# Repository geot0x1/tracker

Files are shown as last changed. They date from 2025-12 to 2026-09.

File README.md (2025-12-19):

# Revision 1 [R1]

### Known issues

The 3.3V power supply remains disabled by the battery charger, which pulls the EN pin low with the PG pin. It must be inverted using a BJT.  

Battery connector pins is wrong.  

Crystal has wrong footprint.  

Memory footprint is wrong, too big for the part.  

RX and TX lines on GSM connection are swapped.  

Change the programming port to 1.5mm pitch.

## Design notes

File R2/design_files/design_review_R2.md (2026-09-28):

# GPS/GSM Tracker (tracker.kicad_pro) — Design Review, Board Rev R2

**Date:** 2026-09-28
**Analysis run:** `analysis/2026-09-28_2106/` (schematic, PCB, cross-domain, EMC, thermal)

## Issues

| # | Severity | Issue | Detail |
|---|---|---|---|
| 1 | BLOCKER | Sourcing gate fails (SS-001) | Only 2/94 components (D1, L3) carry an MPN; no `datasheets/` directory exists. Every pin-level/electrical claim elsewhere is consistency-only, not datasheet-verified. Must reach ≥50% MPN coverage before ordering. |
| 2 | WARNING | R1 known issue never fixed: U2 flash footprint too big | U2 (GD25QxxxEY / GD25Q256EYIGR) uses `Package_SON:WSON-8-1EP_8x6mm_P1.27mm_EP3.4x4.3mm` — byte-for-byte identical to R1. The designer's own R1 README flagged this as wrong; it was not addressed in R2. |
| 3 | WARNING | R1 known issue never fixed: programming port still 2.0mm pitch | J3 is still `Connector_JST:JST_PH_B5B-PH-SM4-TB_1x05-1MP_P2.00mm_Vertical` in both R1 and R2. README asked for 1.5mm pitch. |
| 4 | WARNING | Battery connector polarity swapped vs. R1 — needs physical check | R1: J6 pin1=`+BAT`, pin2=`GND`. R2: pin1=`GND`, pin2=`+BAT` (deliberate swap, not a mirror side-effect). Correct polarity depends on the physical battery pack's own wiring convention, which isn't derivable from the schematic — confirm against the harness before fab. |
| 5 | WARNING | Q1 has zero thermal vias | Reverse-polarity/load-switch MOSFET (Q1, PowerDI3333-8) has 0 of 5 recommended thermal-pad vias. Will run hotter than necessary under sustained load current. |
| 6 | WARNING | Insufficient thermal vias on U1/U2 | U1 (MCU, QFN-48): 8/15 recommended. U2 (flash, WSON-8): 4/9 recommended. Low urgency at the board's modeled 0.067W dissipation, but cheap to fix now. |
| 7 | WARNING | No fiducials on either SMD side (FD-001) | Both F.Cu (50 SMD parts) and B.Cu (42 SMD parts) carry fine-pitch parts (U1 QFN-48 @0.5mm pitch, U12 LGA-12 @0.5mm pitch) with zero fiducials. Add ≥3 per side before ordering assembly. |
| 8 | WARNING | J5 (SIM socket) has no ESD protection | Genuinely user-exposed, hot-pluggable connector with no TVS array on CLK/IO/RST/VCC. Also flagged at a 5:1 signal-to-ground pin ratio (only 1 GND reference for 5 signal/power pins). |
| 9 | WARNING | U11 PCB value field wrong (XV-002) | Schematic value is correctly "BQ25622E"; PCB footprint's value property reads "Untitled_1". Risks wrong-part confusion if a BOM is ever generated from PCB properties. |
| 10 | WARNING | Keepout zones sit under U1 and U12 | Two "no copper pour" zones: one (62.0mm², F.Cu) spans U1 (MCU) and its crystal load-cap/pull-up network (C1–C4, R18–R20); another (6.25mm², B.Cu) spans U12 (accelerometer) and nearby passives (C8/C9/C31/C42, L3, R5/R6, U10). Excludes ground pour from directly under the MCU's decoupling/crystal network unless intentional (e.g. RF/antenna keepout) — confirm design intent before fab. |
| 11 | WARNING | Board-edge clearance below safe minimum | R1 (0.28mm) and D1 (0.31mm) are at/below the ~0.3mm typical safe minimum. |
| 12 | WARNING | EMC: switching harmonics in VHF bands (SW-001) | U8 (LMR51430, 500kHz) harmonics land in the 30–88MHz and 88–216MHz VHF bands. Direct overlap with GNSS L1 (1575.42MHz) or GSM/LTE receive bands is unlikely, but low-VHF radiation from board edges is possible. |
| 13 | WARNING | EMC: filter cutoff too close to switching frequency (EF-001) | Reported for both U8 and U9 — filter component values should be revisited against each regulator's actual switching frequency (500kHz is `freq_source=topology_default`, i.e. assumed, not datasheet-confirmed). |
| 14 | WARNING | EMC: large hot loop on U9 (SW-003) | Switch-node loop area for U9 flagged as large — worth a layout pass to tighten it. |
| 15 | WARNING | EMC: L3 proximity to RTC crystal (ML-001) | L3 (assumed unshielded) sits 13.6mm from Y1 (32.768kHz crystal) — plausible minor coupling risk into the RTC crystal at low urgency given the distance and low switching current. |
| 16 | WARNING | EMC: split ground/power plane stackup (SU-001, GP-001) | All 4 copper layers are typed `signal` rather than having a dedicated GND/PWR plane pair; GND is pour-filled per layer but shared/split with +3V3/+VSYS/+5V zones rather than a continuous reference plane. Return-path continuity is not guaranteed as clean as a classic signal/GND/PWR/signal stackup. Stitching (458 vias present) mitigates this but isn't independently confirmed under the OCTOSPI bus or GSM UART traces. |
| 17 | WARNING | U9 regulator Vref is a heuristic guess, not verified | AP61100Z6 is not in the ~60-family Vref lookup table; the assumed 0.6V reference (giving est. 3.3V output via R13/R14) is plausible but unconfirmed — a wrong assumption here would produce a wrong core rail. |
| 18 | WARNING | BG96 (M1) thermal/current behavior is unmodeled | Classified `type=other` by the analyzer, so it's excluded from every power/thermal model. BG96 GSM transmit bursts are the largest realistic heat/current-transient source on the board and are invisible to this review's tooling — manual check against Quectel's hardware design guide is required. |
| 19 | SUGGESTION | Zero test points (TE-001) | 0 of 149 nets have a dedicated test point. Add test points on key rails (+VBAT, +VSYS, +3V3, +5V, GND) for bring-up/production test. |
| 20 | SUGGESTION | EN pull-ups unusually high (PU-001) | R8/R12 (200kΩ) pull-ups on U8/U9 EN pins are high-impedance — plausible intentional choice for sleep-current minimization, but confirm against each regulator's EN pin leakage spec once datasheets are available. |
| 21 | SUGGESTION | J3/J4 have no ESD protection | Lower risk than J5 (J3 is a board-internal debug header; J4 is an RF path where a TVS would degrade matching), but worth a conscious decision either way. |
| 22 | SUGGESTION | Crystal load caps not verified against spec | C1–C4 (18pF) not checked against Y1/Y3's specific CL requirement — no MPN/datasheet available for either crystal. |

## Not Performed / Review Limits

- Datasheet sync/extraction: not performed (no `datasheets/` directory, no MPNs beyond D1/L3) — every pin-level claim above is consistency-only, not datasheet-verified.
- SPICE simulation: not performed (no ngspice/ltspice/xyce installed).
- Lifecycle audit: not performed (no network/API credentials, and MPN coverage too low to be useful).
- Gerber/drill analysis: not applicable (no gerber export in the project).

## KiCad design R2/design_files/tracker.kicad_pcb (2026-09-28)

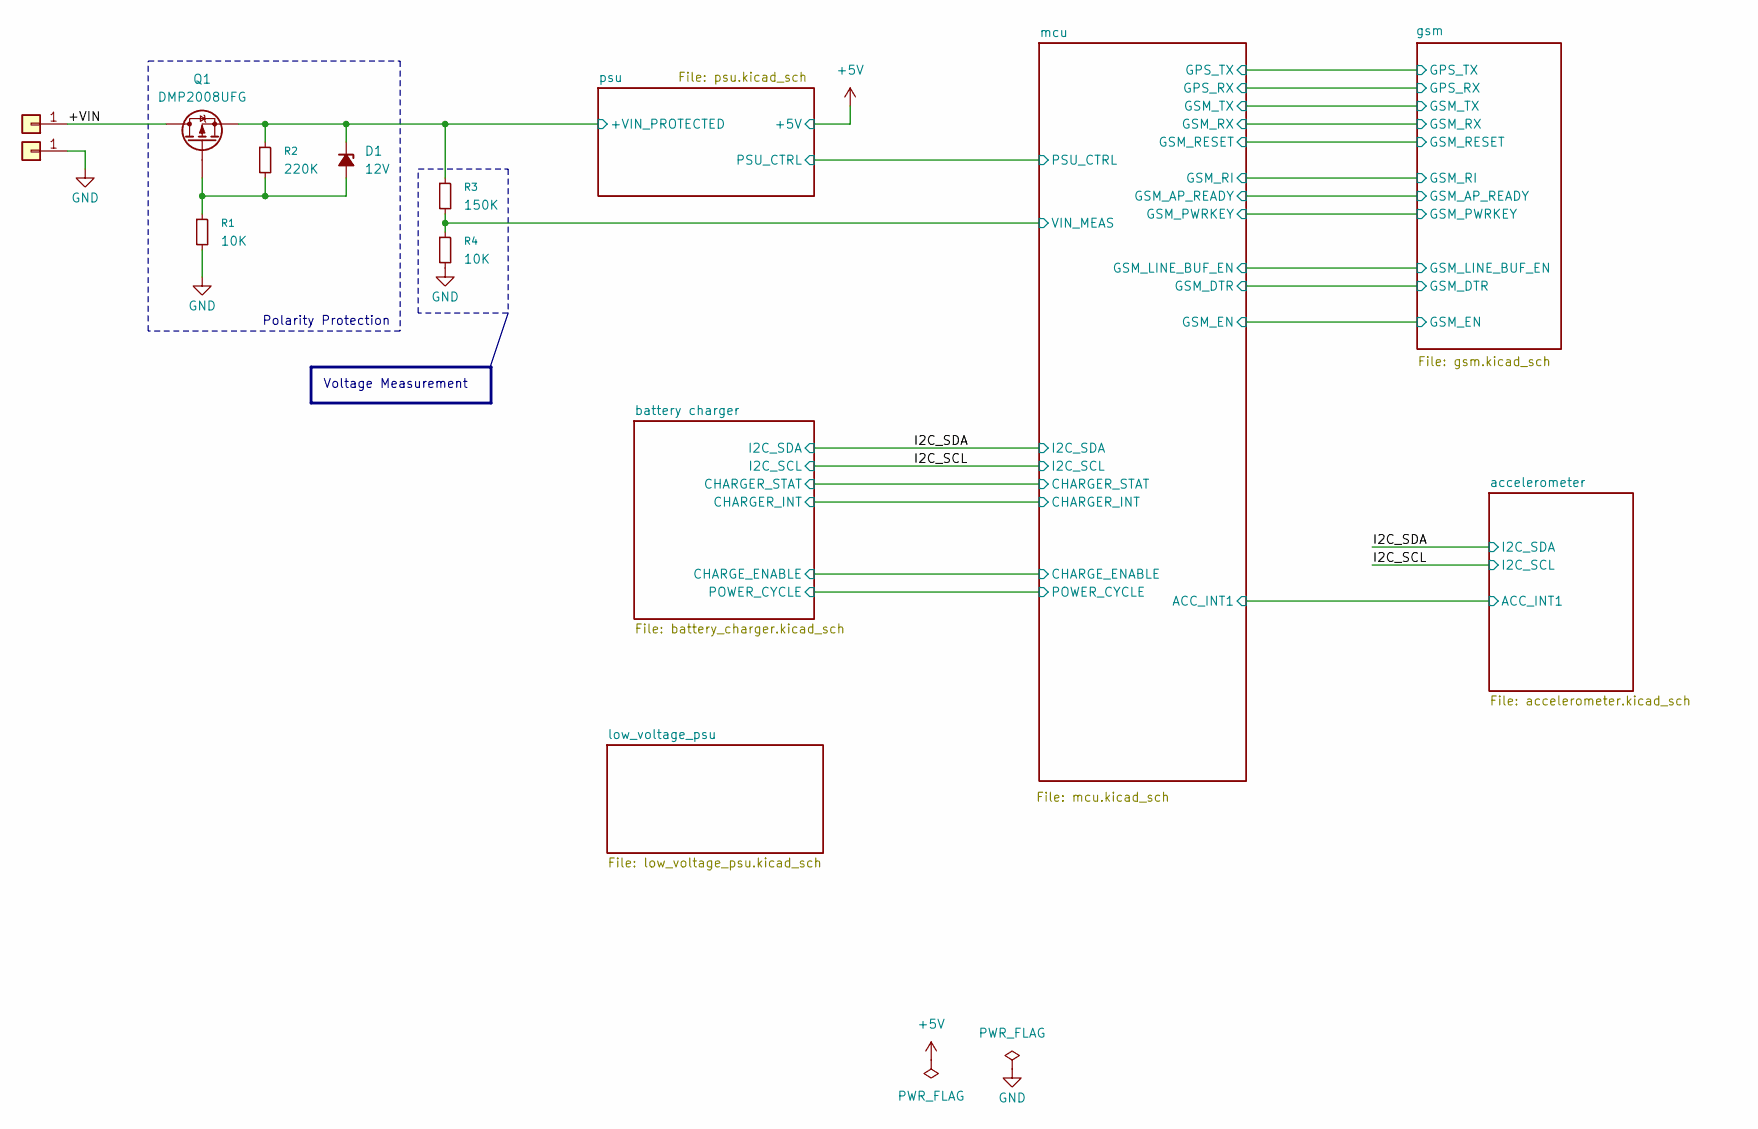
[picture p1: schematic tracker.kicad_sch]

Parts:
D1: 12V; D_SOD-323; PartNo PDZ12B,115
J1, J2: Conn_01x01; pad_smd_1.5x3
Q1: DMP2008UFG; Diodes_PowerDI3333-8
R1, R4: 10K; R_0603_1608Metric
R2: 220K; R_0603_1608Metric
R3: 150K; R_0603_1608Metric

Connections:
/+VIN: J1.1 (Pin_1_1), Q1.5 (D)
/mcu/VIN_MEAS: R3.2, R4.1; also elsewhere on the board
/psu/+VIN_PROTECTED: D1.1 (K), Q1.1 (S), Q1.2 (S), Q1.3 (S), R2.1, R3.1; also elsewhere on the board
GND: J2.1 (Pin_1_1), R1.2, R4.2; also elsewhere on the board
unnamed: D1.2 (A), Q1.4 (G), R1.1, R2.2

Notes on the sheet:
Polarity Protection
Voltage Measurement

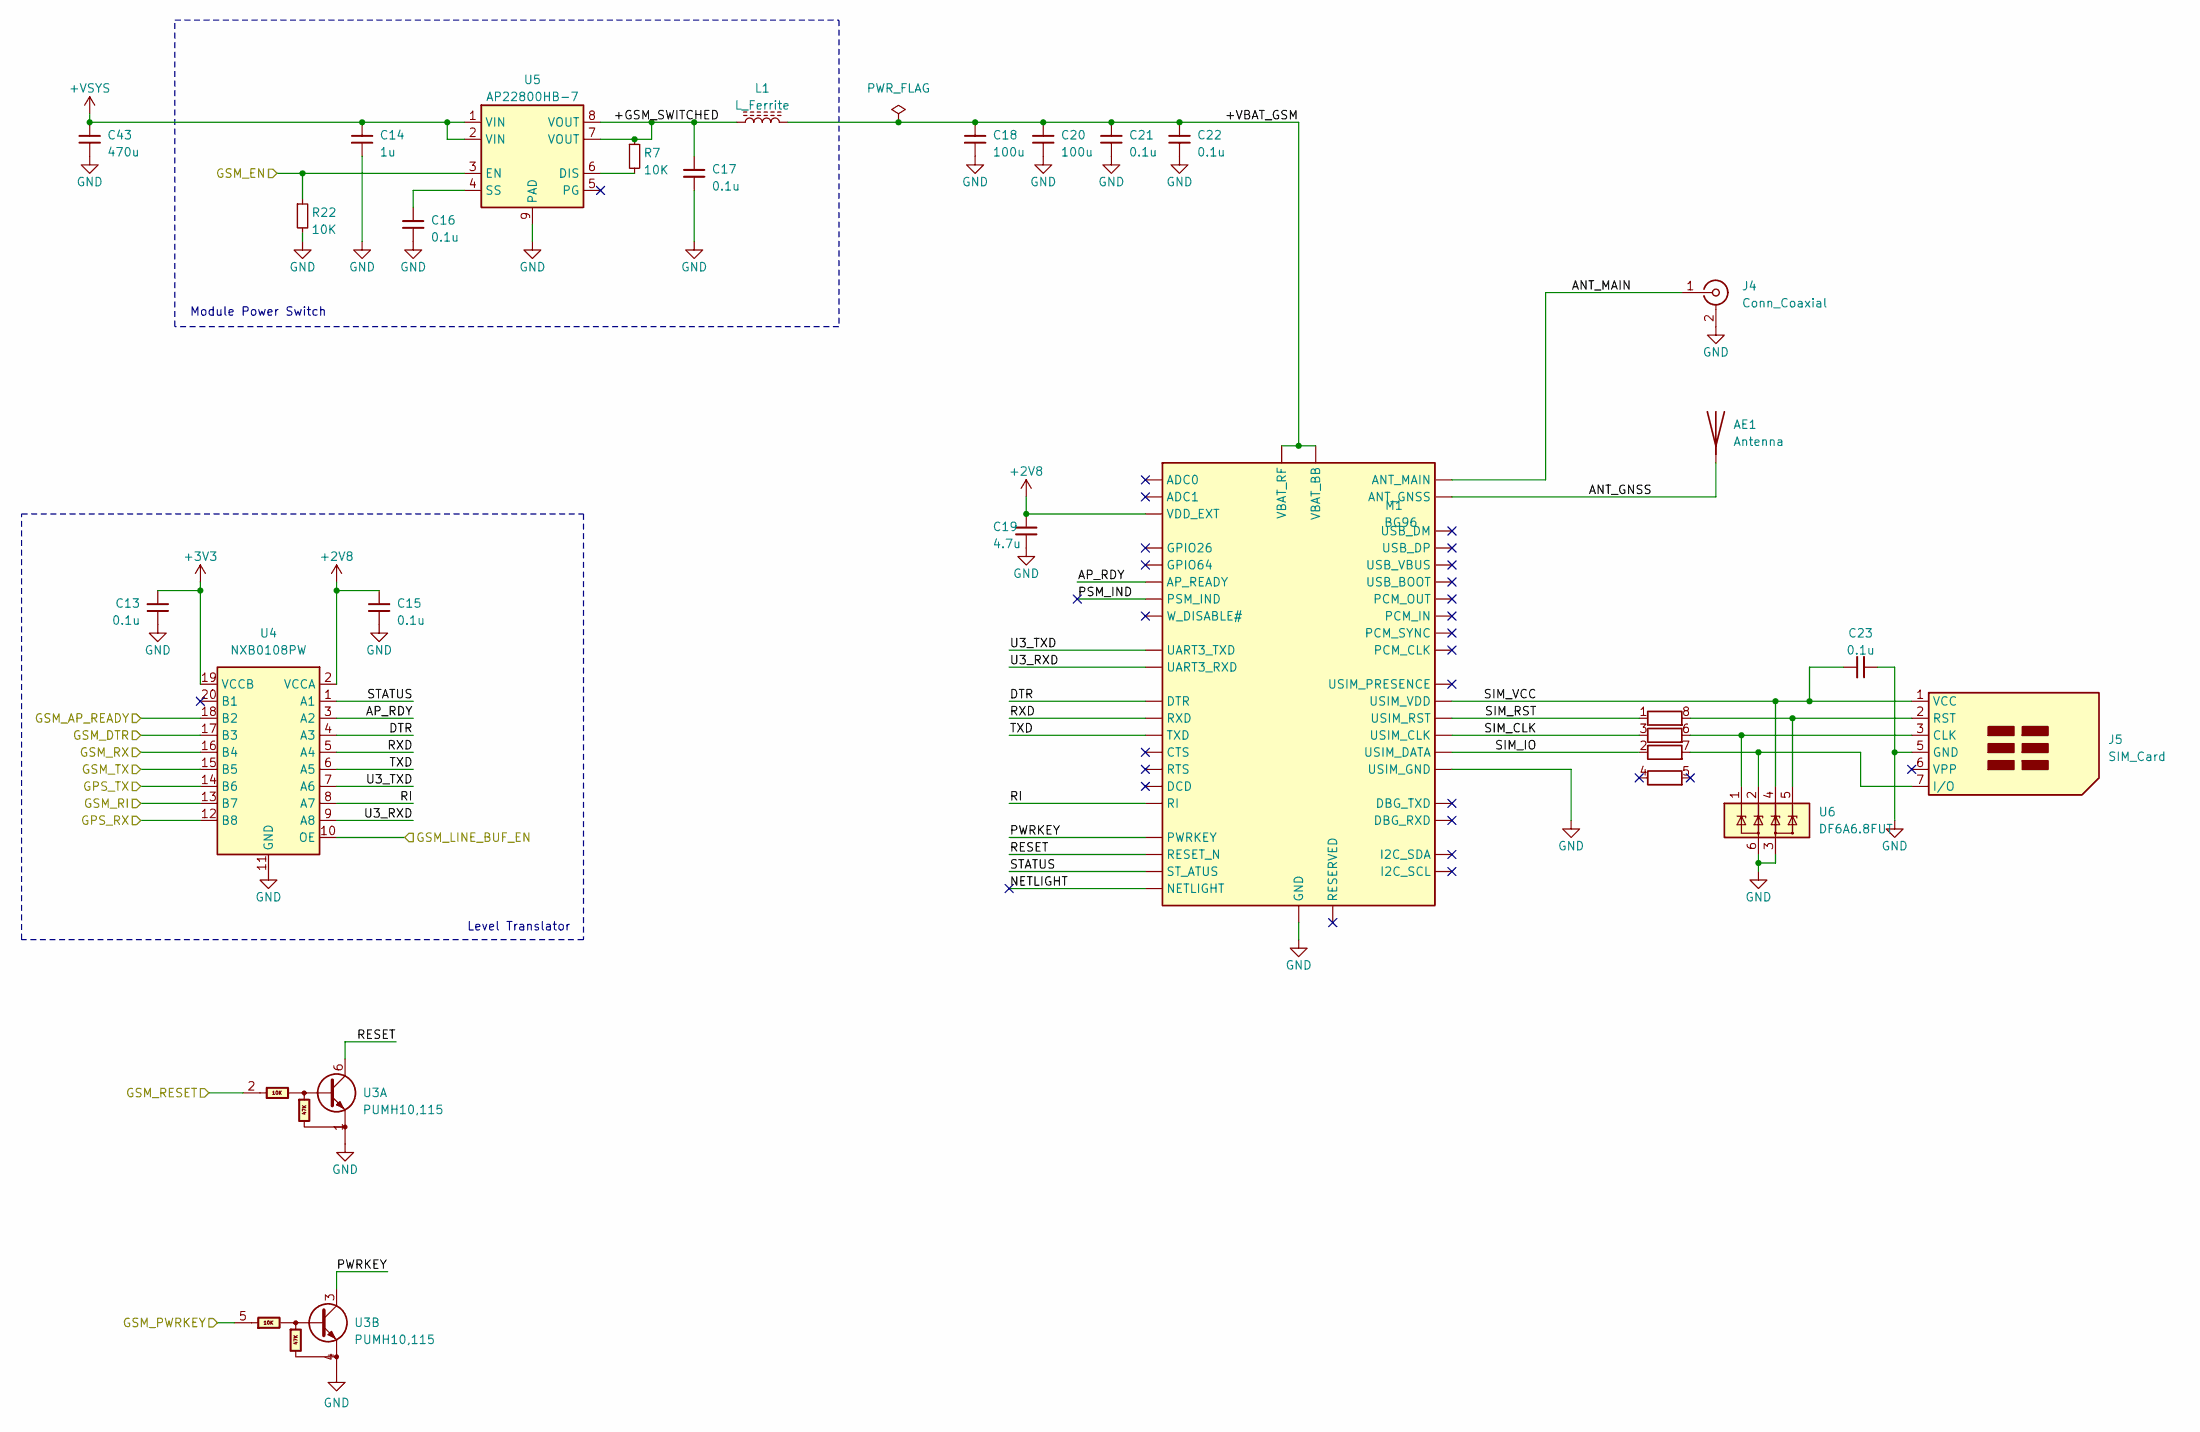
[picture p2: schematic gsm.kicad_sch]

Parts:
AE1: Antenna; APAE1575R1820ABDC1
C13, C15, C16, C17, C21, C22, C23: 0.1u; C_0603_1608Metric
C14: 1u; C_0603_1608Metric
C18, C20: 100u; CP_EIA-6032-20_AVX-F
C19: 4.7u; C_0603_1608Metric
C43: 470u; CP_EIA-7343-31_Kemet-D
J4: Conn_Coaxial; U.FL_Molex_MCRF_73412-0110_Vertical
J5: SIM_Card; microSIM_JAE_SF53S006VCBR2000
L1: L_Ferrite; L_0805_2012Metric
M1: BG96; LGA_BG96
R7, R22: 10K; R_0402_1005Metric
RN1: 22R; R_Array_Concave_4x0603
U3: PUMH10,115; SOT-363_SC-70-6
U4: NXB0108PW; TSSOP-20_4.4x6.5mm_P0.65mm
U5: AP22800HB-7; UDFN2116-8_Diodes
U6: DF6A6.8FUT; SOT-363_SC-70-6

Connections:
+2V8: C15.1, C19.1, M1.29 (VDD_EXT), U4.2 (VCCA)
+3V3: C13.1, U4.19 (VCCB); also elsewhere on the board
+VSYS: C14.1, C43.1, U5.1 (VIN), U5.2 (VIN); also elsewhere on the board
/gsm/+GSM_SWITCHED: C17.1, L1.1, R7.1, U5.7 (VOUT), U5.8 (VOUT)
/gsm/+VBAT_GSM: C18.1, C20.1, C21.1, C22.1, L1.2, M1.32 (VBAT_BB), M1.33 (VBAT_BB), M1.52 (VBAT_RF), M1.53 (VBAT_RF), M1.[32,33] (VBAT_BB), M1.[52,53] (VBAT_RF)
/gsm/ANT_GNSS: AE1.1 (A_1), M1.49 (ANT_GNSS)
/gsm/ANT_MAIN: J4.1 (In), M1.60 (ANT_MAIN)
/gsm/AP_RDY: M1.19 (AP_READY), U4.3 (A2)
/gsm/DTR: M1.30 (DTR), U4.4 (A3)
/gsm/GPS_RX: U4.12 (B8); also elsewhere on the board
/gsm/GPS_TX: U4.14 (B6); also elsewhere on the board
/gsm/GSM_AP_READY: U4.18 (B2); also elsewhere on the board
/gsm/GSM_DTR: U4.17 (B3); also elsewhere on the board
/gsm/GSM_EN: R22.1, U5.3 (EN); also elsewhere on the board
/gsm/GSM_LINE_BUF_EN: U4.10 (OE); also elsewhere on the board
/gsm/GSM_PWRKEY: U3.5; also elsewhere on the board
/gsm/GSM_RESET: U3.2; also elsewhere on the board
/gsm/GSM_RI: U4.13 (B7); also elsewhere on the board
/gsm/GSM_RX: U4.16 (B4); also elsewhere on the board
/gsm/GSM_TX: U4.15 (B5); also elsewhere on the board
/gsm/NETLIGHT: M1.21 (NETLIGHT)
/gsm/PSM_IND: M1.1 (PSM_IND)
/gsm/PWRKEY: M1.15 (PWRKEY), U3.3
/gsm/RESET: M1.17 (RESET_N), U3.6
/gsm/RI: M1.39 (RI), U4.8 (A7)
/gsm/RXD: M1.34 (RXD), U4.5 (A4)
/gsm/SIM_CLK: M1.46 (USIM_CLK), RN1.3 (R3.1)
/gsm/SIM_IO: M1.45 (USIM_DATA), RN1.2 (R2.1)
/gsm/SIM_RST: M1.44 (USIM_RST), RN1.1 (R1.1)
/gsm/SIM_VCC: C23.1, J5.1 (VCC), M1.43 (USIM_VDD), U6.4 (IO3)
/gsm/STATUS: M1.20 (ST_ATUS), U4.1 (A1)
/gsm/TXD: M1.35 (TXD), U4.6 (A5)
/gsm/U3_RXD: M1.28 (UART3_RXD), U4.9 (A8)
/gsm/U3_TXD: M1.27 (UART3_TXD), U4.7 (A6)
GND: C13.2, C14.2, C15.2, C16.2, C17.2, C18.2, C19.2, C20.2, C21.2, C22.2, C23.2, C43.2, J4.2 (Ext), J5.5 (GND), M1.3 (GND), M1.31 (GND), M1.47 (USIM_GND), M1.48 (GND), M1.50 (GND), M1.54 (GND), M1.55 (GND), M1.58 (GND), M1.59 (GND), M1.61 (GND), M1.62 (GND), M1.67 (GND), M1.68 (GND), M1.69 (GND), M1.70 (GND), M1.71 (GND), M1.72 (GND), M1.73 (GND), M1.74 (GND), M1.79 (GND), M1.80 (GND), M1.81 (GND), M1.82 (GND), M1.89 (GND), M1.90 (GND), M1.91 (GND), M1.100 (GND), M1.101 (GND), M1.102 (GND), M1.[3,31,48,50,54,55,5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 (GND), R22.2, U3.1, U3.4, U4.11 (GND), U5.9 (PAD), U6.3 (GND), U6.6 (GND); also elsewhere on the board
unnamed: J5.3 (CLK), RN1.6 (R3.2), U6.1 (IO1)
unnamed: J5.7 (I/O), RN1.7 (R2.2), U6.2 (IO2)
unnamed: J5.2 (RST), RN1.8 (R1.2), U6.5 (IO4)
unnamed: R7.2, U5.6 (DIS)
unnamed: C16.1, U5.4 (SS)

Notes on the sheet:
Module Power Switch
Level Translator

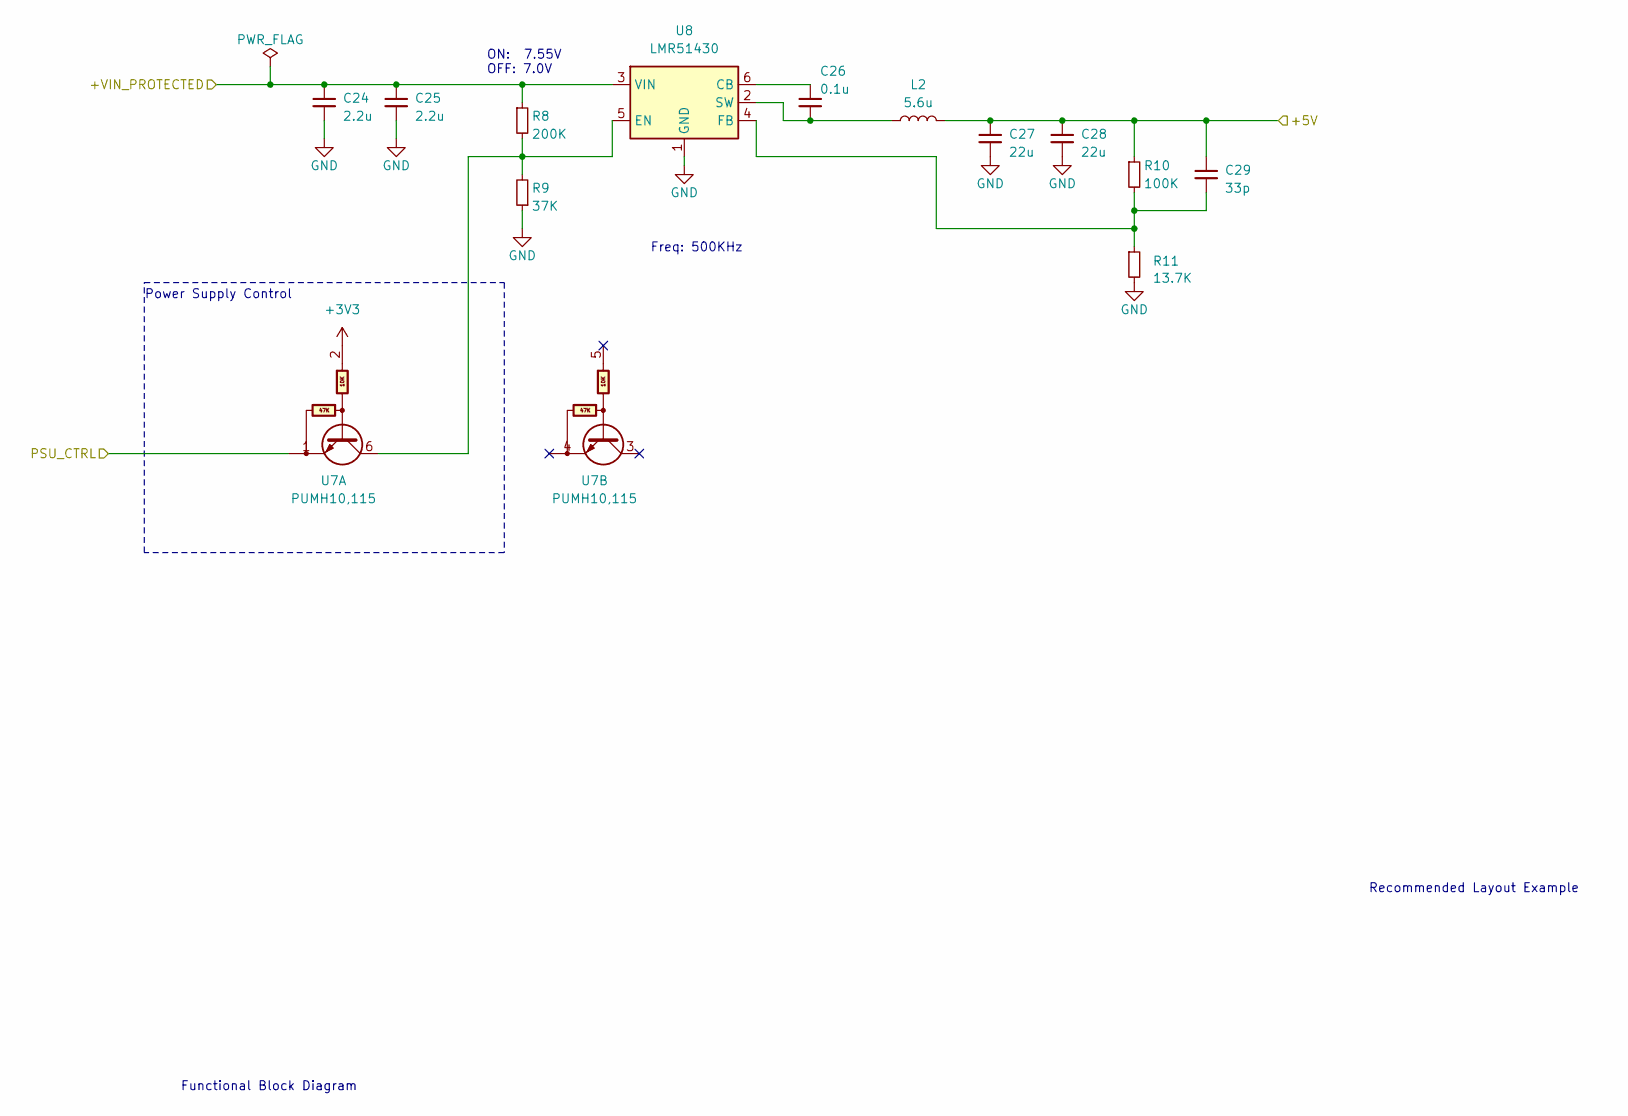
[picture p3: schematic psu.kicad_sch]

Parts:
C24, C25: 2.2u; C_1210_3225Metric
C26: 0.1u; C_0603_1608Metric
C27, C28: 22u; C_1210_3225Metric
C29: 33p; C_0402_1005Metric
L2: 5.6u; L_Bourns_SRN8040TA; Part No SRN8040TA-5R6M
R8: 200K; R_0402_1005Metric
R9: 37K; R_0402_1005Metric
R10: 100K; R_0402_1005Metric
R11: 13.7K; R_0402_1005Metric
U7: PUMH10,115; SOT-363_SC-70-6
U8: LMR51430; SOT-23-6

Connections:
+3V3: U7.2; also elsewhere on the board
+5V: C27.1, C28.1, C29.1, L2.2, R10.1; also elsewhere on the board
/mcu/PSU_CTRL: U7.1; also elsewhere on the board
/psu/+VIN_PROTECTED: C24.1, C25.1, R8.1, U8.3 (VIN); also elsewhere on the board
GND: C24.2, C25.2, C27.2, C28.2, R9.1, R11.2, U8.1 (GND); also elsewhere on the board
unnamed: C26.1, U8.6 (CB)
unnamed: R8.2, R9.2, U7.6, U8.5 (EN)
unnamed: C29.2, R10.2, R11.1, U8.4 (FB)
unnamed: C26.2, L2.1, U8.2 (SW)

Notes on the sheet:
Freq: 500KHz
Functional Block Diagram
ON: 7.55V OFF: 7.0V
Power Supply Control
Recommended Layout Example

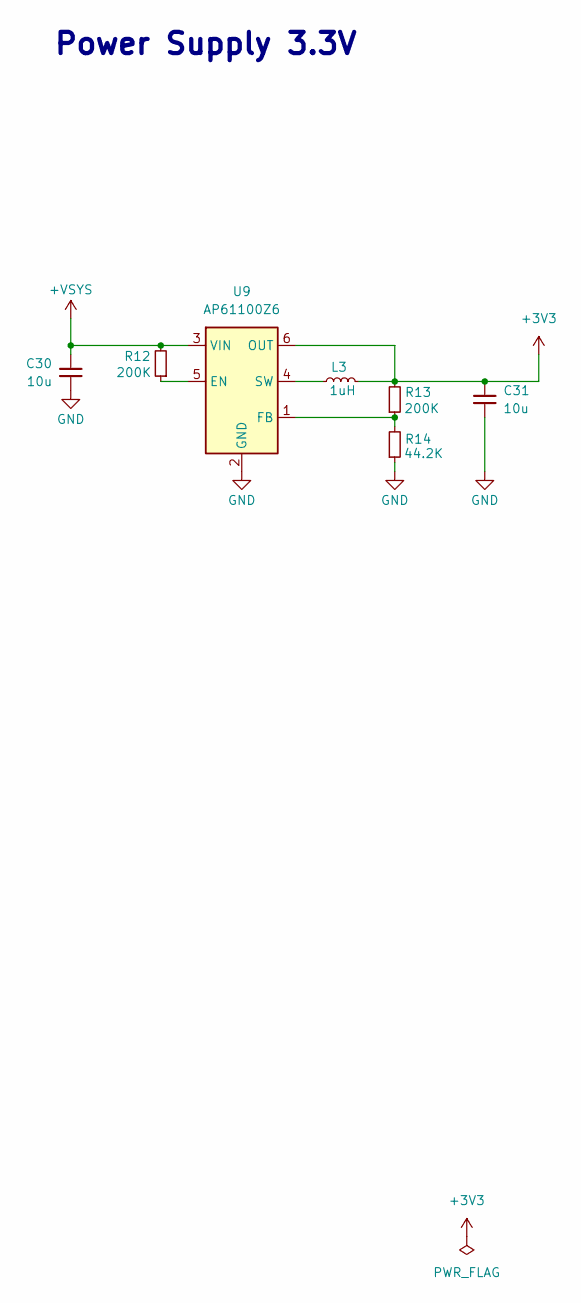
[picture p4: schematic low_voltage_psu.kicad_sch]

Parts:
C30, C31: 10u; C_0805_2012Metric
L3: 1uH; L_0806_2016Metric_TAIYO_YUDEN_SMD; PartNo MAKK2016T1R0M
R12, R13: 200K; R_0402_1005Metric
R14: 44.2K; R_0402_1005Metric
U9: AP61100Z6; SOT-563

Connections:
+3V3: C31.1, L3.2, R13.2, U9.6 (OUT); also elsewhere on the board
+VSYS: C30.1, R12.2, U9.3 (VIN); also elsewhere on the board
GND: C30.2, C31.2, R14.1, U9.2 (GND); also elsewhere on the board
unnamed: R12.1, U9.5 (EN)
unnamed: R13.1, R14.2, U9.1 (FB)
unnamed: L3.1, U9.4 (SW)

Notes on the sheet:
Power Supply 3.3V

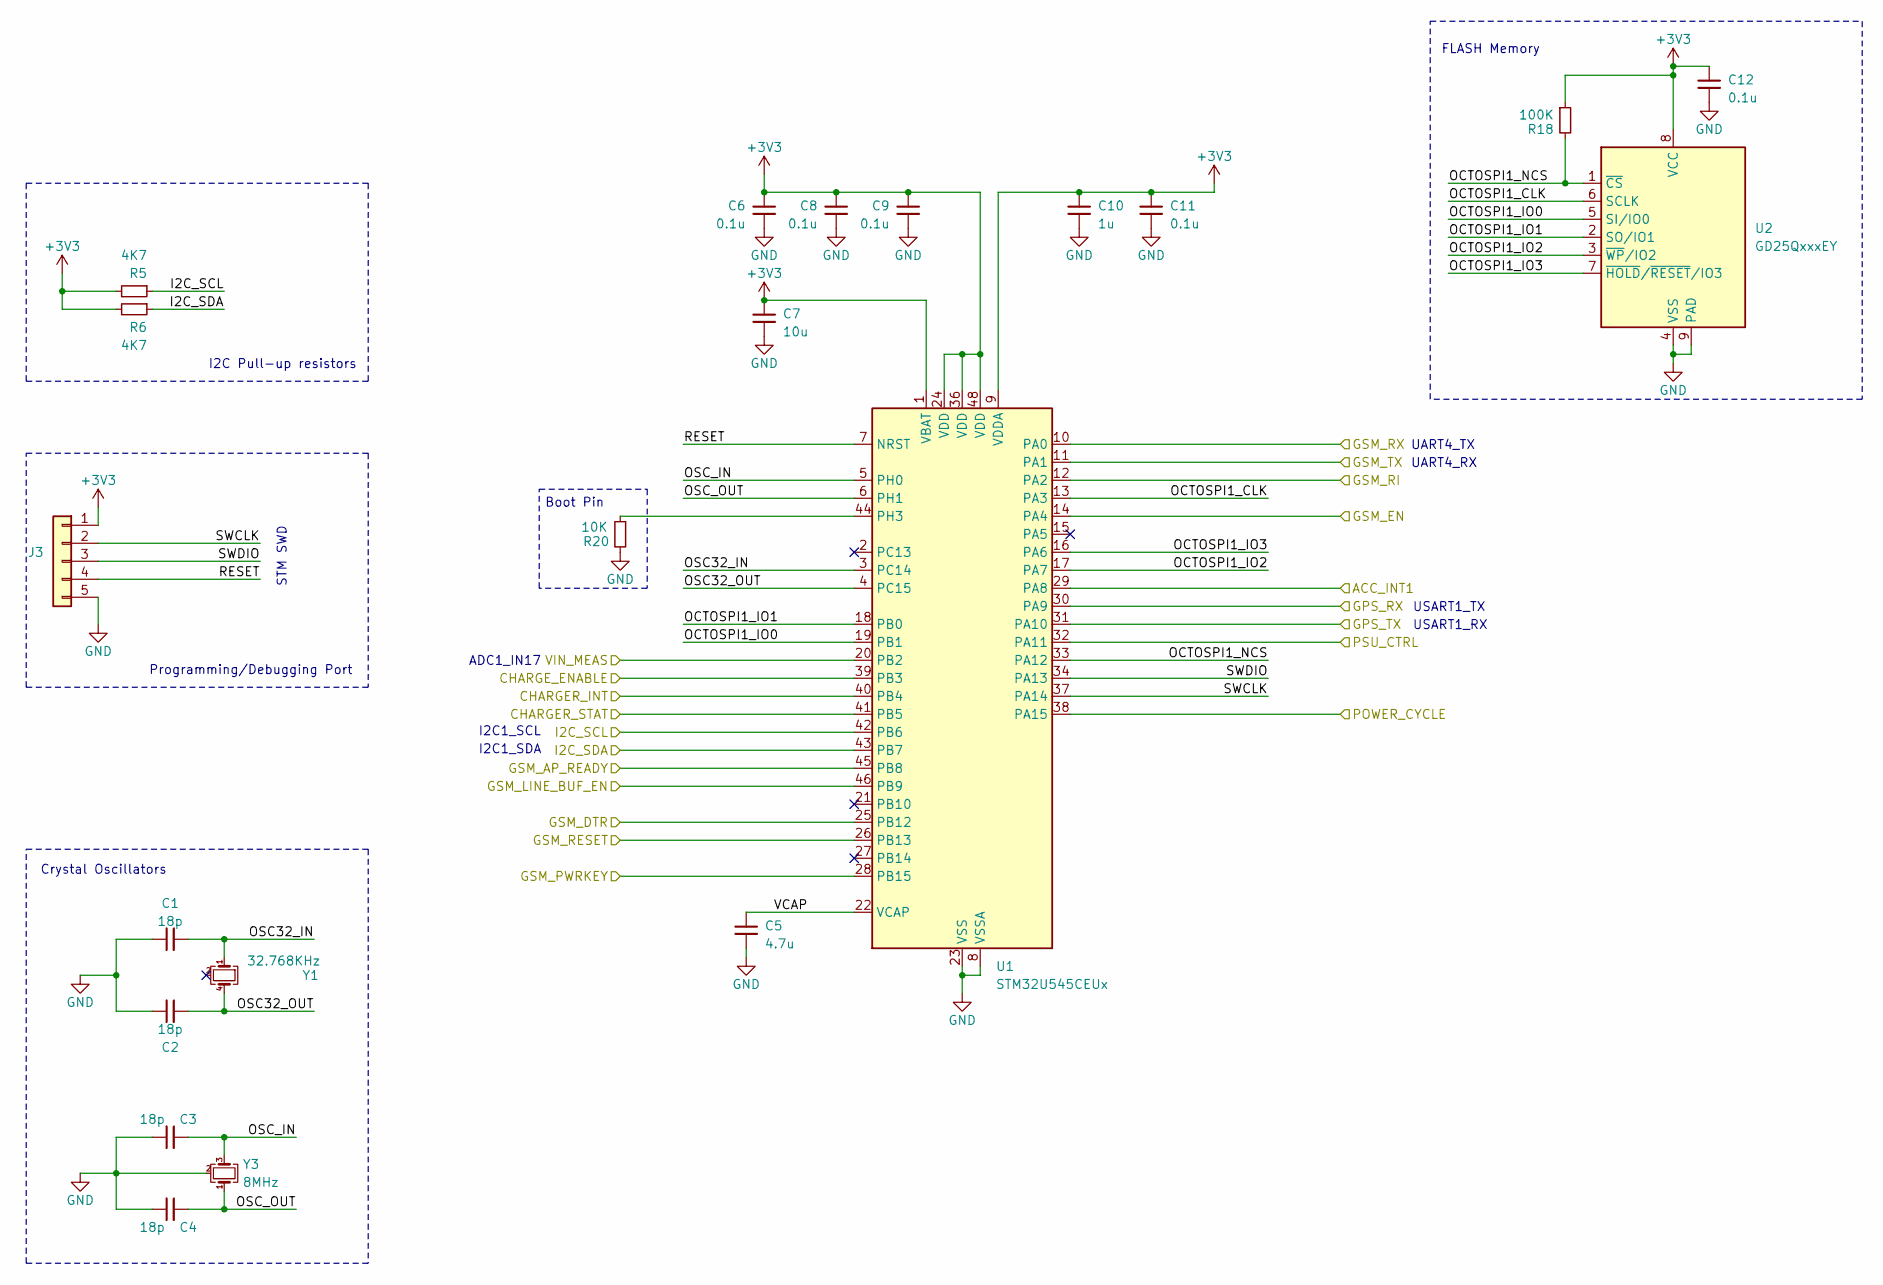
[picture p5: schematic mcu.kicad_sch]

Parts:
C1, C2, C3, C4: 18p; C_0402_1005Metric
C5: 4.7u; C_0603_1608Metric
C6, C8, C9, C11, C12: 0.1u; C_0603_1608Metric
C7: 10u; C_0805_2012Metric
C10: 1u; C_0603_1608Metric
J3: Conn_01x05; JST_PH_B5B-PH-SM4-TB_1x05-1MP_P2.00mm_Vertical
R5, R6: 4K7; R_0402_1005Metric
R18: 100K; R_0402_1005Metric
R20: 10K; R_0402_1005Metric
U1: STM32U545CEUx; QFN-48-1EP_7x7mm_P0.5mm_EP5.6x5.6mm
U2: GD25QxxxEY; WSON-8-1EP_8x6mm_P1.27mm_EP3.4x4.3mm
Y1: 32.768KHz; Crystal_SMD_SeikoEpson_MC146-4Pin_6.7x1.5mm
Y3: 8MHz; Crystal_SMD_SeikoEpson_FA238-4Pin_3.2x2.5mm; JLCPCB C49158086

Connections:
+3V3: C6.1, C7.1, C8.1, C9.1, C10.1, C11.1, C12.1, J3.1, R5.2, R6.2, R18.1, U1.1 (VBAT), U1.9 (VDDA), U1.24 (VDD), U1.36 (VDD), U1.48 (VDD), U2.8 (VCC); also elsewhere on the board
/I2C_SCL: R5.1, U1.42 (PB6); also elsewhere on the board
/I2C_SDA: R6.1, U1.43 (PB7); also elsewhere on the board
/accelerometer/ACC_INT1: U1.29 (PA8); also elsewhere on the board
/battery charger/CHARGER_INT: U1.40 (PB4); also elsewhere on the board
/battery charger/CHARGER_STAT: U1.41 (PB5); also elsewhere on the board
/battery charger/CHARGE_ENABLE: U1.39 (PB3); also elsewhere on the board
/battery charger/POWER_CYCLE: U1.38 (PA15); also elsewhere on the board
/gsm/GPS_RX: U1.30 (PA9); also elsewhere on the board
/gsm/GPS_TX: U1.31 (PA10); also elsewhere on the board
/gsm/GSM_AP_READY: U1.45 (PB8); also elsewhere on the board
/gsm/GSM_DTR: U1.25 (PB12); also elsewhere on the board
/gsm/GSM_EN: U1.14 (PA4); also elsewhere on the board
/gsm/GSM_LINE_BUF_EN: U1.46 (PB9); also elsewhere on the board
/gsm/GSM_PWRKEY: U1.28 (PB15); also elsewhere on the board
/gsm/GSM_RESET: U1.26 (PB13); also elsewhere on the board
/gsm/GSM_RI: U1.12 (PA2); also elsewhere on the board
/gsm/GSM_RX: U1.10 (PA0); also elsewhere on the board
/gsm/GSM_TX: U1.11 (PA1); also elsewhere on the board
/mcu/OCTOSPI1_CLK: U1.13 (PA3), U2.6 (SCLK)
/mcu/OCTOSPI1_IO0: U1.19 (PB1), U2.5 (SI/IO0)
/mcu/OCTOSPI1_IO1: U1.18 (PB0), U2.2 (SO/IO1)
/mcu/OCTOSPI1_IO2: U1.17 (PA7), U2.3 (~WP/IO2)
/mcu/OCTOSPI1_IO3: U1.16 (PA6), U2.7 (~HOLD/~RESET/IO3)
/mcu/OCTOSPI1_NCS: R18.2, U1.33 (PA12), U2.1 (~CS)
/mcu/OSC32_IN: C1.2, U1.3 (PC14), Y1.1
/mcu/OSC32_OUT: C2.1, U1.4 (PC15), Y1.4
/mcu/OSC_IN: C3.2, U1.5 (PH0), Y3.3
/mcu/OSC_OUT: C4.2, U1.6 (PH1), Y3.1
/mcu/PSU_CTRL: U1.32 (PA11); also elsewhere on the board
/mcu/RESET: J3.4, U1.7 (NRST)
/mcu/SWCLK: J3.2, U1.37 (PA14)
/mcu/SWDIO: J3.3, U1.34 (PA13)
/mcu/VCAP: C5.1, U1.22 (VCAP)
/mcu/VIN_MEAS: U1.20 (PB2); also elsewhere on the board
GND: C1.1, C2.2, C3.1, C4.1, C5.2, C6.2, C7.2, C8.2, C9.2, C10.2, C11.2, C12.2, J3.5, R20.2, U1.8 (VSSA), U1.23 (VSS), U1.35 (VSS), U1.47 (VSS), U1.49 (VSS), U2.4 (VSS), U2.9 (PAD), Y3.2 (G), Y3.4 (G); also elsewhere on the board
unnamed: R20.1, U1.44 (PH3)

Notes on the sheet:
USART1_RX
UART4_TX
STM SWD
Boot Pin
I2C1_SCL
I2C1_SDA
Crystal Oscillators
UART4_RX
USART1_TX
Programming/Debugging Port
FLASH Memory
ADC1_IN17
I2C Pull-up resistors

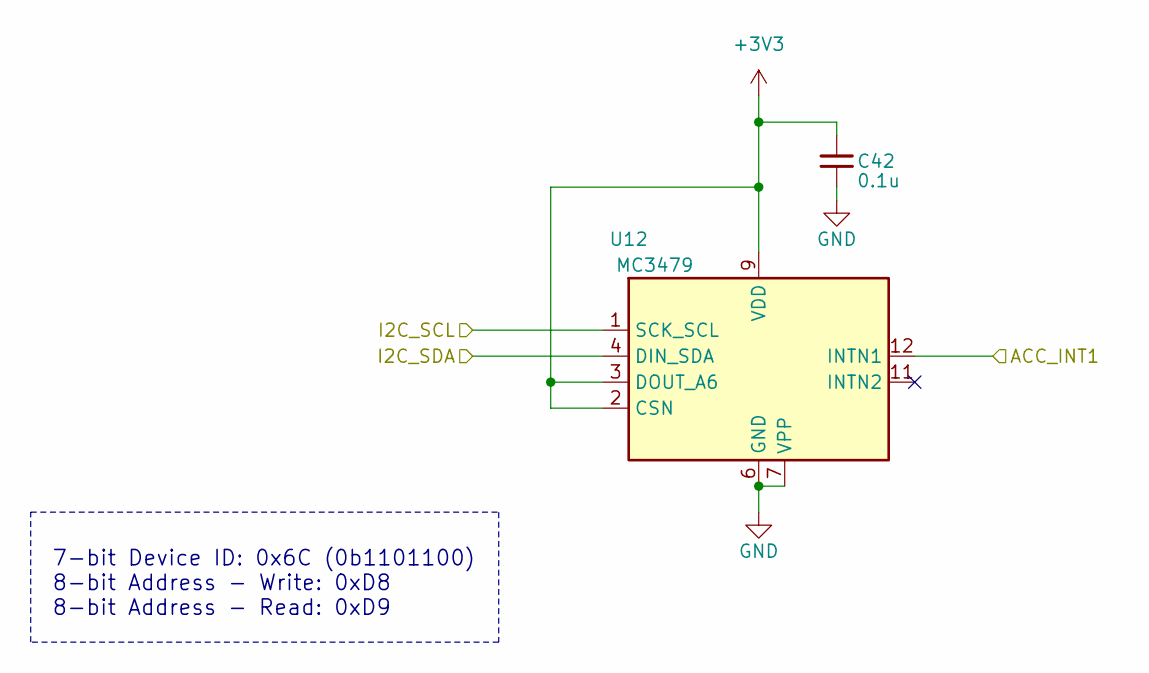
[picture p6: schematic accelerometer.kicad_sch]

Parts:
C42: 0.1u; C_0603_1608Metric
U12: MC3479; LGA-12_2x2mm_P0.5mm

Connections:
+3V3: C42.1, U12.2 (CSN), U12.3 (DOUT_A6), U12.9 (VDD); also elsewhere on the board
/I2C_SCL: U12.1 (SCK_SCL); also elsewhere on the board
/I2C_SDA: U12.4 (DIN_SDA); also elsewhere on the board
/accelerometer/ACC_INT1: U12.12 (INTN1); also elsewhere on the board
GND: C42.2, U12.6 (GND), U12.7 (VPP); also elsewhere on the board

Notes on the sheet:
7-bit Device ID: 0x6C (0b1101100) 8-bit Address - Write: 0xD8 8-bit Address - Read: 0xD9

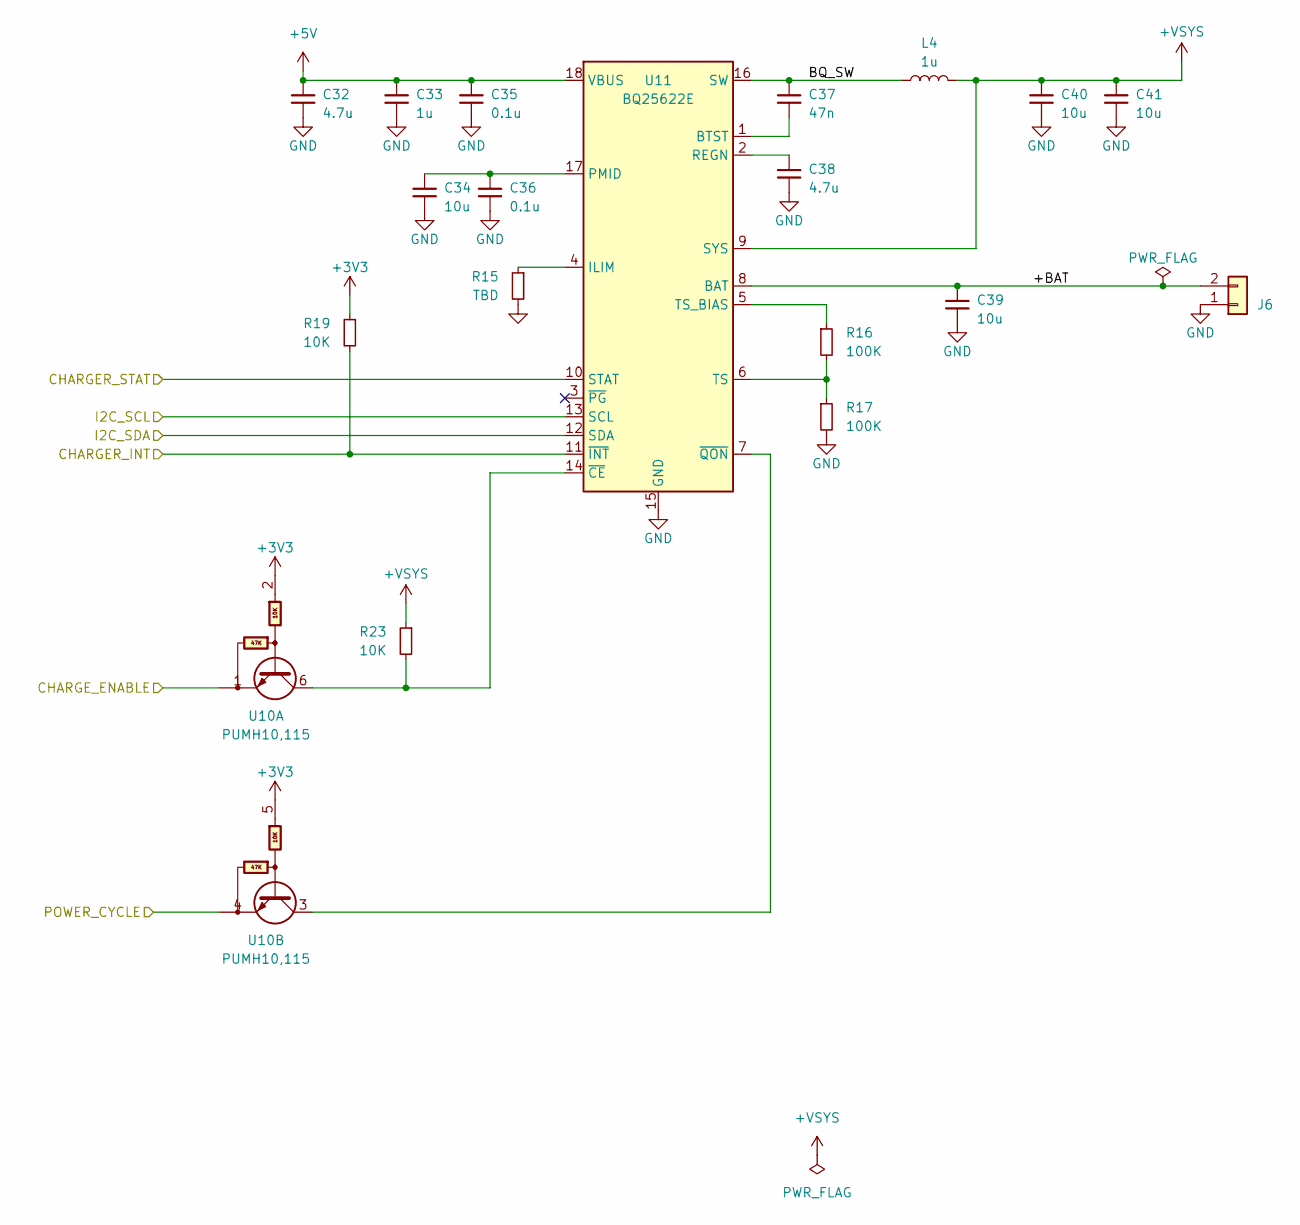
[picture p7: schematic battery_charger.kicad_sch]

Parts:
C32: 4.7u; C_0805_2012Metric
C33: 1u; C_0603_1608Metric
C34, C39, C40, C41: 10u; C_0805_2012Metric
C35, C36: 0.1u; C_0603_1608Metric
C37: 47n; C_0402_1005Metric
C38: 4.7u; C_0603_1608Metric
J6: Conn_01x02; JST_XH_B2B-XH-A_1x02_P2.50mm_Vertical
L4: 1u; Inductor_TYA252012
R15: TBD; R_0402_1005Metric
R16, R17: 100K; R_0402_1005Metric
R19, R23: 10K; R_0402_1005Metric
U10: PUMH10,115; SOT-363_SC-70-6
U11: BQ25622E

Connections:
+3V3: R19.1, U10.2, U10.5; also elsewhere on the board
+5V: C32.1, C33.1, C35.1, U11.18 (VBUS); also elsewhere on the board
+VSYS: C40.1, C41.1, L4.2, R23.1, U11.9 (SYS); also elsewhere on the board
/I2C_SCL: U11.13 (SCL); also elsewhere on the board
/I2C_SDA: U11.12 (SDA); also elsewhere on the board
/battery charger/+BAT: C39.1, J6.2, U11.8 (BAT)
/battery charger/BQ_SW: C37.1, L4.1, U11.16 (SW)
/battery charger/CHARGER_INT: R19.2, U11.11 (~INT); also elsewhere on the board
/battery charger/CHARGER_STAT: U11.10 (STAT); also elsewhere on the board
/battery charger/CHARGE_ENABLE: U10.1; also elsewhere on the board
/battery charger/POWER_CYCLE: U10.4; also elsewhere on the board
GND: C32.2, C33.2, C34.2, C35.2, C36.2, C38.2, C39.2, C40.2, C41.2, J6.1, R15.2, R17.2, U11.15 (GND); also elsewhere on the board
unnamed: C37.2, U11.1 (BTST)
unnamed: R15.1, U11.4 (ILIM)
unnamed: C34.1, C36.1, U11.17 (PMID)
unnamed: C38.1, U11.2 (REGN)
unnamed: R16.2, R17.1, U11.6 (TS)
unnamed: R16.1, U11.5 (TS_BIAS)
unnamed: R23.2, U10.6, U11.14 (~CE)
unnamed: U10.3, U11.7 (~QON)

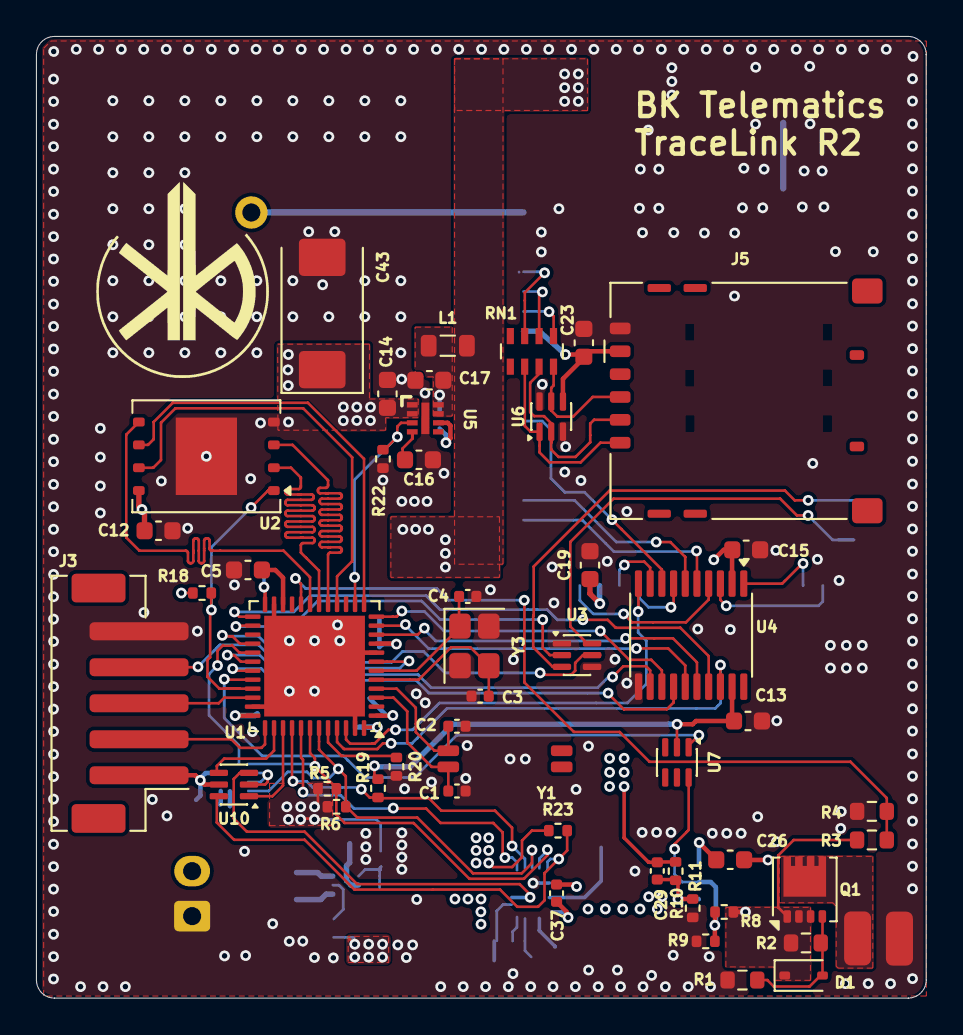
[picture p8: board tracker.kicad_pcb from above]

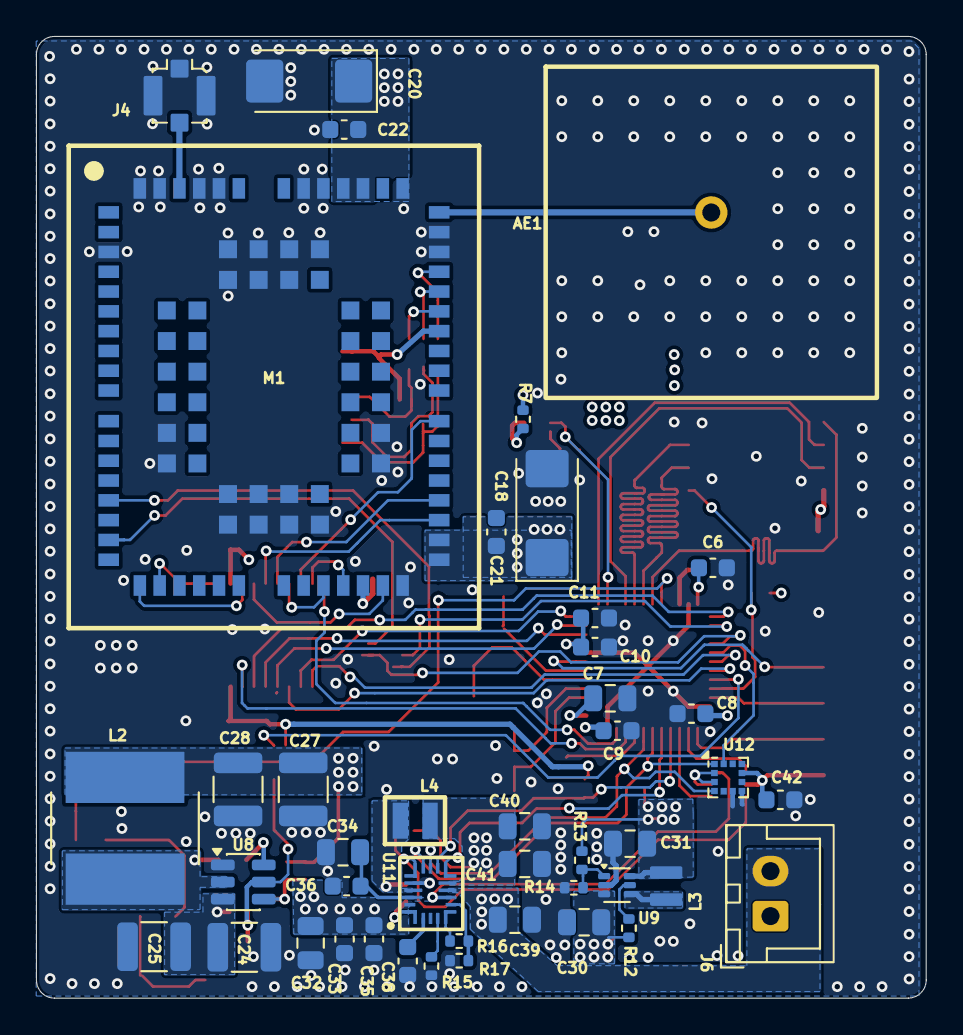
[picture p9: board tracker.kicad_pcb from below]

Board: 4 copper layers, 49.4 x 53.4 mm, 94 parts (44 on the bottom side), 83 nets.

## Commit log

2025-10-28 first version
    [accelerometer.kicad_sch, battery_charger.kicad_sch, gsm.kicad_sch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]
2025-10-28 rename dir
    [accelerometer.kicad_sch, battery_charger.kicad_sch, gsm.kicad_sch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]
2025-11-02 Added CS pullup
    [mcu.kicad_sch, tracker.kicad_pcb]
2025-11-13 First review.
    [battery_charger.kicad_sch, gsm.kicad_sch, mcu.kicad_sch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]
2025-11-13 Added gerbers
2025-11-26 Changed values in schematic
    [psu.kicad_sch]
2025-12-19 Added files into R1 directory
    [accelerometer.kicad_sch, battery_charger.kicad_sch, gsm.kicad_sch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]
2025-12-23 Added R2
    [accelerometer.kicad_sch, battery_charger.kicad_sch, gsm.kicad_sch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]
2026-01-01 added capacitor 470u
    [gsm.kicad_sch, tracker.kicad_pcb]
2026-09-24 Refactor code structure for improved readability and maintainability
    [accelerometer.kicad_sch, battery_charger.kicad_sch, gsm.kicad_sch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]
2026-09-24 Enhance design settings in tracker.kicad_pro
    - Added options to disable default application for footprint barcodes, dimensions, fields, shapes, and text.
    - Expanded zone settings with additional parameters including border display style, corner radius, fill mode, and thermal relief specifications.
    - Introduced new warnings for footprint symbol field mismatches and missing tuning profiles.
    - Updated track settings to include options for centered tracks on vias and tuning profile track geometries.
    [tracker.kicad_pcb]
2026-09-28 Update designators and component properties in schematic and project files
    [tracker.kicad_sch]
2026-09-28 Add design review documentation for Board Rev R2 and update used designators in project file
